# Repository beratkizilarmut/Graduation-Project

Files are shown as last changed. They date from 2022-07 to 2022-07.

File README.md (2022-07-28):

# Graduation-Project

2021/2022

Graduation Project Personal Works of

Berat Kizilarmut, Electronics Engineering Student at Gebze Technical University

Ömer Emre Polat, Electronics Engineering Student at Gebze Technical University

In daily life, users are integrating wearable technology products into their lives
more and more day by day. This technological revolution, which started with the daily
use of smart phones, continues to accelerate in the market with products such as smart
watches and smart wristbands. Smart glasses, which are new types of wearable
technology products that include augmented reality in the past years, have not received
a great acceptance in the market yet. The reason why these wearable technology
products, which bring the border between reality and information technologies closer
together, have not yet found a place in the market, is that smart glasses and their
derivatives are not attractive to users in terms of their design and their costs are
relatively high. For this reason, the project was made on the design of an external smart
glasses apparatus with a lower cost and where the users can change the onboard
software according to their needs and their desired functionality

Development board used in the Bluetooth Based External Smart Glass Apparatus is ESP32-WROOM-32D. Development environment is Platform.IO and operating system is FreeRTOS.

Graduation project report provided is written in Turkish.

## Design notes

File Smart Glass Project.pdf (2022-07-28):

# Introduction

In daily life, users are integrating wearable technology products into their lives more and more

day by day. This technological revolution, which started with the daily use of smart phones,

continues to accelerate in the market with products such as smart watches and wristbands.

Smart glasses, which are new types of wearable technology products that include augmented

reality in the past years, have not received a great acceptance in the market yet. The reason why

these wearable technology products, which bring the border between reality and information

technologies closer together, have not yet found a place in the market, is that smart glasses and

their derivatives are not attractive to users in terms of design and their costs are high. Our top

priority is accessibility and customization to solve this very problem.

# Current Implementation

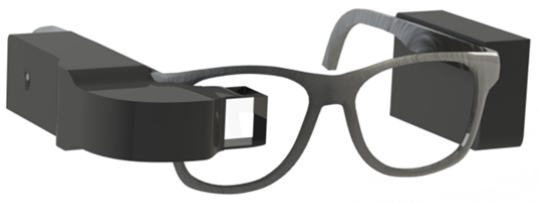
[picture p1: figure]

Current implementation which was our graduation project from electronics engineering is made

up from two distinct modules. First module contains the microcontroller unit, capacitive touch

user interface and the optical package that user view's. Second module contains the battery,

voltage boost and battery charging circuit. Apart from the body of the smart glass, every

component used is off the shelf and is open to further optimization opportunities.

# Use Cases

Main use case for the current implementation is displaying necessary smart phone information

to the user seamlessly, such as time and application notifications. Improvement for this use case

would be implementing support for other applications such as maps which would be useful for

drivers to check their map without obstructing their view. Another use case could be that for

deaf people, the device could perform speech recognition through the use of a speech

recognition API with the Wi-Fi of the phone and display the recognized speech to the deaf

person.

# Technical Details

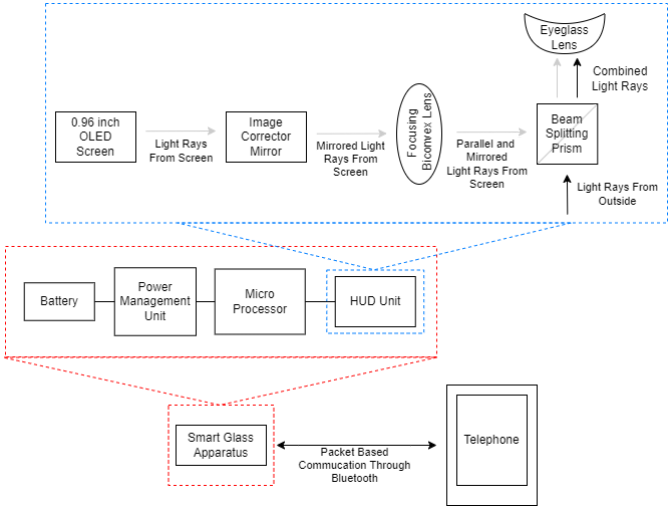
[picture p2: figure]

The software of the microcontroller, which is 'Espressif ESP32-WROOM-32D', is written in an

efficiency-oriented manner aiming for low power consumption. Software has been developed

with the help of the 'Arduino Framework' on the 'C++' software language and the 'PlatformIO'

plug-in using 'FreeRTOS' open source operating system. The advantage of this operating system

type is that more than one process can be performed at the same time, various processes can be

run on selected cores, and task assignment for operations. Power Delivery Unit consists of

'Adafruit Powerboost 1000C' Li-Ion Battery Charging and Voltage Booster circuit and the

2000mAh 3.7V Lithium-Ion battery. As for the optical details, a generic 0.96 inch OLED screen is

located at the back of the optical housing. Image rendered at the display is reflected upon the

mirror to direct it to the biconvex lens. Image with focal length aligned to human perception is

combined with background image at the beam-splitting prism and this combined image is then

viewed by the user.

# Improvement Plans

Microcontroller development board that is currently used is not utilized fully GPIO-wise. An

integrated circuit board with this very microprocessor and desired display embedded in one will

massively cut the physical size of the board thus decrease the footprint of the smart glass body.

By utilizing mirrored images on the display itself, need for the correcting view mirror can be eliminated and overall size of the smart glass body can be decreased even more. These two past

improvement plans will decrease the already low cost of the product. Rather than further cost

and size improvements, electronics improvement which open the doors to more hardware

intensive wearable technology implementations. With better hardware protocols such as

'Android Auto' and 'Apple CarPlay' can be utilized to give users heads-up display experience for

any application they want for example maps.

# Final Words

As a duo of engineers, we are interested in improving our project even further to fill the wearable

technology deficiency for glasses wearing tech enthusiasts. We are interested and open to

improve ourselves further in embedded system technologies.

# Contacts

Berat Kızılarmut - beratkizilarmut@gmail.com - +905393040726

Ömer Emre Polat - omeremrepolat1@hotmail.com - +905439034947

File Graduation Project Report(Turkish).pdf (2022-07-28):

T.C.

## GEBZE TEKNİK ÜNİVERSİTESİ

## MÜHENDİSLİK FAKÜLTESİ

## BLUETOOTH TABANLI HARİCİ AKILLI

## GÖZLÜK APARATI

## ÖMER EMRE POLAT

## BERAT KIZILARMUT

## LİSANS BİTİRME-II PROJESİ RAPORU

## ELEKTRONİK MÜHENDİSLİĞİ BÖLÜMÜ

### DANIŞMANI

### DR. TUBA GÖZEL

## GEBZE

2022

T.R.

## GEBZE TECHNICAL UNIVERSITY

## ENGINEERING FACULTY

## BLUETOOTH BASED EXTERNAL

## SMART GLASS APPARATUS

## ÖMER EMRE POLAT

## BERAT KIZILARMUT

## UNDERGRADUATE THESIS

## GRADUATION-II PROJECT REPORT

## ELECTRONICS ENGINEERING DEPARTMENT

### THESIS SUPERVISOR

### DR. TUBA GÖZEL

## GEBZE

2022

GEBZE TEKNİK
ÜNİVERSİTESİ | LİSANS JÜRİ ONAY FORMU
GTÜ Mühendislik Fakültesi Yönetim Kurulu’nun | / | /.. | tarih ve
..………/ | sayılı kararıyla oluşturulan jüri tarafından | / | /.. | tarihinde tez
savunma | sınavı | yapılan | | ’ın | tez | çalışması
| Anabilim Dalında LİSANS tezi olarak kabul edilmiştir.

JÜRİ

ÜYE

(TEZ DANIŞMANI) :

ÜYE | :
ÜYE | :

ONAY
Gebze Teknik Üniversitesi | Enstitüsü Yönetim Kurulu’nun
...…/.…../ | tarih ve ….…/ | sayılı kararı.

i

## ÖZET

Günlük hayatta kullanıcılar giyilebilir teknoloji ürünlerini hayatlarına günden

güne daha fazla entegre etmektedirler. Akıllı telefonların günlük kullanımı ile başlayan

bu teknolojik devrim, akıllı saat ve akıllı bileklik gibi ürünler ile markette

ivmelenmeye devam etmektedir. Google ve Microsoft gibi firmaların da geçtiğimiz

yıllarda artırılmış gerçeklik barındıran yeni tür giyilebilir teknoloji ürünleri olan akıllı

gözlükler ise henüz markette büyük bir kabul görmemiştir. Kullanıcıların gerçeklik ile

bilgi teknolojileri arasındaki sınırı birbirine yakınlaştıran bu giyilebilir teknoloji

ürünlerinin markette henüz bir yer edememesinin sebebi akıllı gözlük ve türevlerinin

tasarım olarak kullanıcılara çekici gelmemesi ve maliyetlerinin yüksek olmasıdır. Bu

sebeple yapılan proje daha düşük maliyette ve kullanıcıların istediği işleve göre

yazılımını değiştirebileceği bir harici akıllı gözlük aparatı tasarlanması üzerine

yapılmıştır.

Anahtar Kelimeler: Giyilebilir Teknoloji, Akıllı Gözlük, Gömülü Sistemler,

Optik

ii

## SUMMARY

In daily life, users are integrating wearable technology products into their lives

more and more day by day. This technological revolution, which started with the daily

use of smart phones, continues to accelerate in the market with products such as smart

watches and smart wristbands. Smart glasses, which are new types of wearable

technology products that include augmented reality in the past years, have not received

a great acceptance in the market yet. The reason why these wearable technology

products, which bring the border between reality and information technologies closer

together, have not yet found a place in the market, is that smart glasses and their

derivatives are not attractive to users in terms of their design and their costs are

relatively high. For this reason, the project was made on the design of an external smart

glasses apparatus with a lower cost and where the users can change the onboard

software according to their needs and their desired functionality.

Key Words: Wearable Tech, Smart Eyeglasses, Embedded Systems, Optics

iii

## TEŞEKKÜR

Başta, lisans eğitimimizde ve akademik hayatımızda desteğini ve yardımlarını

hiçbir zaman esirgemeyip bilgisi ile bu çalışmanın oluşmasının yolunu açan

danışmanımız Dr. Tuba Gözel’e ve atölyelerini tarafımız kullanımına açan Gebze Teknik Üniversitesi Robotik ve Otomasyon Kulübü’ne teşekkürlerimizi sunarız.

iv

## İÇİNDEKİLER

| Sayfa
ÖZET | i
SUMMARY | ii
TEŞEKKÜR | iii
İÇİNDEKİLER | iv
SİMGELER ve KISALTMALAR DİZİNİ | v
ŞEKİLLER DİZİNİ | vi
TABLOLAR DİZİNİ | vii
1. GİRİŞ 1.1. Projenin Amacı, Katkısı ve İçeriği 1.2. Projenin Kapsamı 1.3. Literatür Taraması 1.3.1. Işın Ayırıcı Prizma 1.3.2. Kapasitif Dokunmatik Arayüz | 1 2 2 2 3 3
2. PROJE YÖNTEMİ | 4
2.1. Malzeme Listesi
2.1.1. Mikro Denetleyici Ünitesi
2.1.2. Ekran Ünitesi
2.1.3. Batarya
2.1.4. Batarya Şarj ve Yükseltici Ünitesi
2.1.5. Işın Ayırıcı Prizma
2.1.6. Lens
2.1.7. Bütçe
2.2. Donanım Tasarımı
2.3. Mikro Denetleyici Yazılımı
2.3.1. Ana İşlevsellik
2.3.2. Gözlük İşlevselliği Kütüphanesi
2.3.3. Görüntü İşlevselliği Kütüphanesi
2.3.4. Bluetooth İşlevselliği Kütüphanesi
2.3.5. Giriş Çıkış İşlevselliği Kütüphanesi
2.4. Mobil Cihaz Uygulaması

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
3. Ürün Değerlendirilmesi 3.1. Mobil Cihaz Uygulaması 3.2. Bluetooth Tabanlı Harici Akıllı Gözlük Ünitesi | 14 14 15
4. Sonuçlar ve Yorumlar | 16
5. Öneriler ve Geliştirmeler | 17
KAYNAKÇA | 17

v

## SİMGELER ve KISALTMALAR DİZİNİ

Simgeler ve

Kısaltmalar

Açıklamalar

RISC | : Reduced Instruction Set Architecture (İndirgenmiş Komut Takımlı
| Mimari)
SPI | : Serial Peripheral Interface (Seri Çevre Birimi Arayüzü)
OLED | : Organic Light Emitting Diode (Organik Işık Saçılımlı Diyot)
HUD | : Head-Up Display (Baş Üstü Göstergesi)
Wi-Fi | : Wireless Field (Kablosuz Ağ)

vi

## ŞEKİLLER DİZİNİ

Şekil No: | Sayfa
1.1: | Bluetooth Tabanlı Harici Akıllı Gözlük Aparatı | 1
1.3.1.1: | Işın Ayırıcı Prizma çalışma prensibi diyagramı | 3
2.1: | Akıllı Gözlük Aparatı Bağlantı ve İletişim Diyagramı | 4
2.2.1: | Donanım Tasarımı Üç Boyutlu Modeli | 8
2.2.2: | Ekran, ayna, lens ve ışın ayırıcı prizma geometrik diyagramı | 9
2.3.1: | ESP32-WROOM-32D Mikro Denetleyici | 9
2.3.2: | Mikro Denetleyici Yazılım Akış Diyagramı | 10
2.4.1: | Mobil Uygulama Yazılım Akış Diyagramı | 13
3.1.1: | Yapılan Mobil Uygulamanın Emülatör Üzerinde Denenmesi | 14
3.2.1: | Kullanıcı tarafından görülen görüntü örneği | 15
4.1: | Bluetooth Tabanlı Harici Akıllı Gözlük Aparatı | 16

vii

## TABLOLAR DİZİNİ

Tablo No: | Sayfa
2.1.7.1: | Bluetooth Tabanlı Harici Akıllı Gözlük Aparatı Malzeme Listesi

ve Bütçesi

7

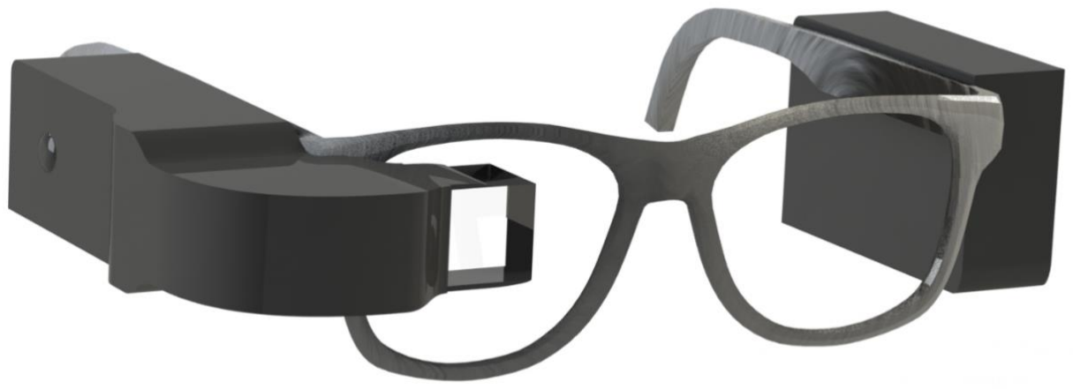
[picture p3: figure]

1

## 1. GİRİŞ

Günlük hayatta kullanıcılar giyilebilir teknoloji ürünlerini hayatlarına günden

güne daha fazla entegre etmektedirler. Akıllı telefonların günlük kullanımı ile başlayan

bu teknolojik devrim, akıllı saat ve bileklik gibi ürünler ile markette ivmelenmeye

devam etmektedir. Google ve Microsoft gibi firmaların da geçtiğimiz yıllarda

artırılmış gerçeklik barındıran yeni tür giyilebilir teknoloji ürünleri olan akıllı

gözlükler ise henüz markette büyük bir kabul görmemiştir. Kullanıcıların gerçeklik ile

bilgi teknolojileri arasındaki sınırı birbirine yakınlaştıran bu giyilebilir teknoloji

ürünlerinin markette henüz bir yer edememesinin sebebi akıllı gözlük ve türevlerinin

tasarım olarak kullanıcılara çekici gelmemesi ve maliyetlerinin yüksek olmasıdır.

Şekil 1.1: Bluetooth Tabanlı Harici Akıllı Gözlük Aparatı

2

## 1.1. Projenin Amacı, Katkısı ve İçeriği

Her telefona ve her gözlüğe uyum sağlayabilecek, kullanımı kolay ve gündelik

hayata negatif etki etmeyecek bir harici akıllı gözlük aparatı çözümü üretmek. Bu

gözlük aparatı kullanıcının gözüne polarize optik çözümleri ile sahip olunan bilgileri

yansıtacak. Gözlüğün işlem merkezi olarak ‘RISC’ temelli bir mikro denetleyici

ünitesi kullanılacak. Mikro denetleyici ünitesinde gömülü durumda bulunan

'Bluetooth' modülü aracılığı ile gözlüğün, 'Bluetooth' uyumlu telefon arasında iletişimi

sağlanacak. Gözlüğün konfigürasyonları telefonda bulunan uygulama aracılığı ile

yapılacak. Modüler teknolojisi ile kullanıcının tercihindeki gözlüğe adapte edilebilen

bir ürün olacak.

## 1.2. Projenin Kapsamı

Giyilebilir teknoloji marketindeki bir sonraki adım olan akıllı gözlük

çözümlerinin kullanıcılara daha uygun fiyatlarla ve daha geniş bir gözlük yelpazesine

uygulanabilir hale getirilmesi.

Proje sayesinde:

-Daha ulaşılabilir fiyatlarda bir akıllı gözlük çözümü.

-Kullanıcıların kendi gözlüklerine uyum sağlayan modüler bir yapı.

-Modüler yapısından dolayı tamir edilebilir olması.

-Açık kaynak temelli olması.

-Yazılımsal olarak modüler olması, modifikasyonlara ve kişiselleştirmelere açık

olması.

## 1.3. Literatür Taraması

Bluetooth Tabanlı Harici Akıllı Gözlük Aparatı Projesinin geliştirme aşamasında

araştırılan ve projede kullanılan teknolojilerin özet bilgileri verilmiştir.

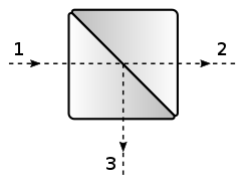
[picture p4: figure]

3

### 1.3.1. Işın Ayırıcı Prizma

Işın ayırıcı [1], bir ışık hüzmesini ikiye ayıran bir optik araçtır. Genellikle yapı

olarak iki adet yarım küp prizmanın araya çeşitli kaplamalar eklenip yapıştırılması ile üretilir. İki yarım prizma arasındaki kaplama prizmanın ışın bölme oranını (çoğunlukla

%50 ye %50) ve etkili bulunduğu dalga boyu gibi parametreleri ayarlamak için

kullanılır. Işın ayırıcı prizmalar hem gelen ışık hüzmesini iki ayrı hüzmeye bölebilir,

Şekil 1.3.1.1’de gösterildiği gibi, hem de ayrı yönlerden gelen iki ışık hüzmelerini

birleştirip tek bir yönden iletebilirler.

Şekil 1.3.1.1: Işın Ayırıcı Prizma çalışma prensibi diyagramı

### 1.3.2. Kapasitif Dokunmatik Arayüz

Kapasitif Dokunmatik Arayüzler [2] bir insan dokunuşu veya iletken

dokunuşunu tespit edebilen iletişim arayüzleridir. Kapasitif arayüze temas

edildiğinde temas noktasında küçük bir miktar elektrik yükü çekilerek işlevsel bir

kapasitör oluşturulur. Bu oluşan kapasitör ve kapasitans değeri bir mikro denetleyici

tarafından tespit edilebilir ve bir giriş arayüzü olarak kullanılabilir. Bu metot

mekanik, hareket eden parçalar bulundurmadığı için uzun ömürlü bir buton tipi

olarak sunulmaktadır.

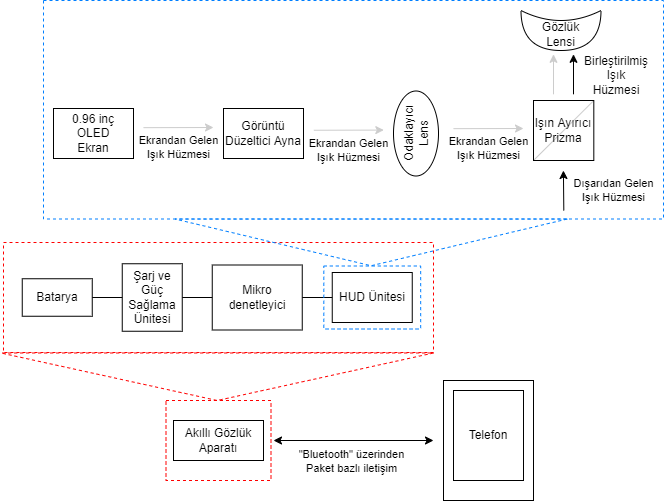
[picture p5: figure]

4

## 2. PROJE YÖNTEMİ

Şekil 2.1: Akıllı Gözlük Aparatı Bağlantı ve İletişim Diyagramı

Bluetooth Tabanlı Harici Akıllı Gözlük Aparatı Projesi, diyagramı yukarıda Şekil

2.1’de verilmiş bulunan, çalışma yöntemi olarak akıllı telefonda bulunan mobil

uygulama sayesinde ‘Bluetooth’ aracılığı ile mikro denetleyici ünitesi ile iletişim

kuracaktır. Mobil uygulama tarafından alınan veriler mikro denetleyici tarafından

işlenecek ve optik işlemler sonucunda kullanıcının gözüne yansıtılacaktır. Bluetooth

Tabanlı Harici Akıllı Gözlük Aparatı Projesi üç alana bölünüp incelenmiştir. Raporda

malzeme listesinin ardından öncelikle optik çözüm, kullanıcı ara yüzü ve elektronik

donanımı barındıran fiziksel donanım tasarımı incelenecektir. Bu kısım mikro

denetleyici mobil uygulama aracılığı ile gönderilen verileri kullanarak gözlük görüntü

işlevselliklerini düzenleyecek ve çıkış verecektir. Dahilinde bulunan batarya ve güç

üniteleri ise hem mikro denetleyiciyi hem de görüntü işlevlerine gerekli enerjiyi

sağlayacaktır. Fiziksel yapının ardından mikro denetleyici ünitesinde çalışmakta olan

‘Bluetooth’ iletişim işlevselliği, görüntü çıktı fonksiyonları ve kullanıcı ara yüz

5

fonksiyonları gibi işlevsellikleri barındıran mikro denetleyici yazılımı incelenecektir.

Ardından bu kısımlardan sonuncusu olan akıllı telefon ile mikro denetleyici ünitesi

arasında iletişimi sağlayan, telefondan işlevsellikler için gerekli olan bilgilerin

alınmasını sağlayan ve kullanıcı ayarlarının yapılmasına olanak sağlayan mobil

uygulama incelenecektir.

## 2.1. Malzeme Listesi

Bluetooth Tabanlı Harici Akıllı Gözlük Aparatı Projesinde kullanılmak üzere

seçilen parçalar ve seçilme nedenleri.

### 2.1.1. Mikro Denetleyici Ünitesi

Mikro denetleyici ünitesi olarak, kendi 'Bluetooth' ve 'Wi-Fi' iletişim ünitesi

içinde olması, kapasitif sezi özelliğine sahip olması, boyut faktörünün kullanımımıza

uygun olması, performansına göre güç harcaması az olması, fiyatının uygun olması

ve bulunabilirliği kolay olması sebeplerinden dolayı ESP32-WROOM-32D [3]

modeli seçilmiştir.

### 2.1.2. Ekran Ünitesi

Görüntü çıkışı alınması için ekran ünitesi olarak küçük boyutu, ‘SPI’ iletişim

protokolü, yüksek parlaklığı ve uygun fiyatından dolayı markasız 0,96 inç OLED

80x160 SPI Ekran [4] seçilmiştir.

### 2.1.3. Batarya

Sisteme güç sağlaması için batarya elimizde bulunduğu için 3.7V 2000mAh Lityum-İyon bir batarya kullanılmıştır. Batarya tercihi olarak Lityum-İyon batarya

seçilmesinin sebebi diğer batarya teknolojilerine göre birim boyuta kıyaslandığında

enerji yoğunluğunun yüksek olmasıdır.

6

### 2.1.4. Batarya Şarj ve Yükseltici Ünitesi

Lityum-İyon tip batarya kullanıldığı için, lityum-iyon bataryaların özel

gereksinimlerini sağlayan ve kendi içerisinde 3.7V gerilimi mikro denetleyicinin

kullandığı 5V gerilime yükselten Adafruit Powerboost 1000C Batarya Şarj ve Yükseltici Ünitesi elimizde bulunduğu için ve gereksinimleri sağladığı için

kullanılmıştır.

### 2.1.5. Işın Ayırıcı Prizma

Optik işlemlerde 18 mm en, 18 mm boy ve 18 mm yüksekliğe sahip, 50:50

bölme oranına sahip ve görünür ışık dalga boyunda işlevselliğe sahip bir ışın ayırıcı

prizma kullanılmıştır. Geçirgenlik oranı olarak 50:50 seçilmesinin sebebi ekran

parlaklığı ile ortam ışığı seviyesinin denk tutulmasının amaçlanmasıdır.

### 2.1.6. Lens

Optik işlemlerde kullanıcının gözünün yorulmaması için görüntünün odak noktasını kaydıran 45 mm odak uzaklığına sahip bir lens kullanılmıştır. Özel tasarım

lens üretilmesinin masraflı olmasından dolayı projedeki optik çözümlere uyum

sağlayabilen özelliklere sahip ‘Google Cardboard’ yapay gerçeklik gözlüğünün

lensleri tercih edilmiştir.

### 2.1.7. Bütçe

Bluetooth Tabanlı Harici Akıllı Gözlük Aparatı Projesinde kullanılan

malzemeler ve fiyatları Tablo 2.1.7.1’de verilmiştir.

7

Tablo 2.1.7.1 Bluetooth Tabanlı Harici Akıllı Gözlük Aparatı Malzeme

Listesi ve Bütçesi

Ürün ismi | Adet | Fiyat | Link
ESP32-WROOM-32D | 1 | 131,2 7 TL | https://www.direnc.net/esp32-wroom-32d-wifi-bluetooth-gelistirme-modulu
PowerBoo st 1000C | 1 | 327,2 6 TL | https://www.adafruit.com/product/2465
3.7V 2000 mAh Li-Ion Batarya | 1 | 108,5 9 TL | https://www.direnc.net/37v-2000-mah-li-polymer-pil
tinylab 3D 1.75 mm Siyah PLA Filament | 1 | 239,9 9 TL | https://www.amazon.com.tr/tinylab-1-75-Siyah-PLA-Filament/dp/B08DJ3XC3W/
0.96 inch SPI OLED Ekran | 1 | 104,3 7 TL | https://www.direnc.net/096-inch-oled-arduino-spi-tft-ekran
18*18*18 Işın Ayırıcı Prizma | 1 | 156,4 1 TL | https://tr.aliexpress.com/item/1005001279808206 .html
Google Cardboard 25mm Lens | 1 | 9,90 TL | https://urun.n11.com/giyilebilir-teknoloji-aksesuarlari/toptan-25mm-sanal-gerceklik-gozlugu-google-cardboard-lens-25-mm-P377565747
5*5 Pleksi Ayna | 1 | 20,40 TL | https://urun.n11.com/diger/3mm-gumus-renk-ayna-pleksi-istediginiz-olcude-lazer-kesim-P441922073
TOPLAM | | 1097,80 TL

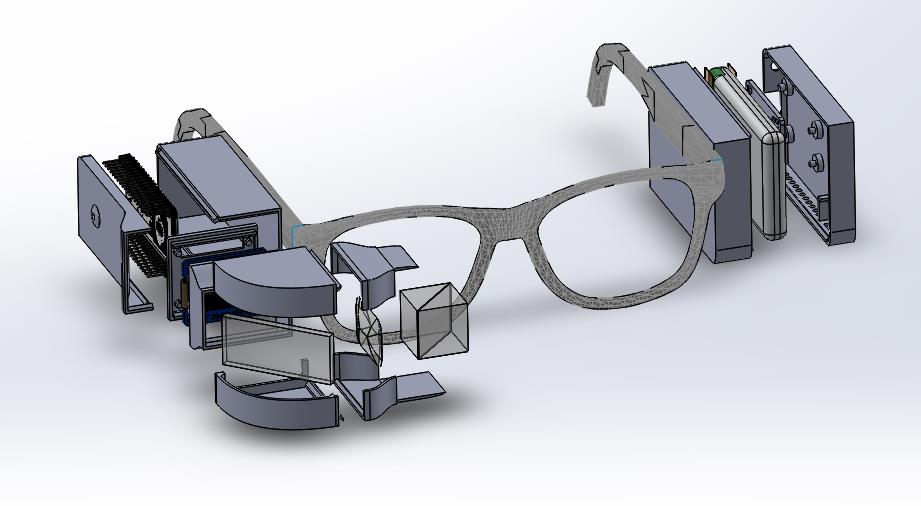
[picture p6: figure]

8

## 2.2. Donanım Tasarımı

Şekil 2.2.1: Donanım Tasarımı Üç Boyutlu Modeli

Bluetooth Tabanlı Harici Akıllı Gözlük Aparatı Projesinin işlevselliği için

kullanımına karar verilen elektronik ve optik malzemelerin bir araya getirilebilmesi

için bir donanım tasarımı yapılmıştır. Tasarım için Bilgisayar Destekli Tasarım

Programı olan ‘Solidworks’ kullanılmış, tasarımlar üç boyutlu yazıcı aracılığı ile PLA malzeme kullanılarak üretilmiştir. Donanım üç parçaya ayrılarak incelenmiştir. İlk

parça olarak mikro denetleyici ünitesi ve kapasitif dokunmatik ara yüzü barındıran bölme oluşturulmuştur. İkinci parça olarak Lityum-İyon batarya, Batarya Şarj ve

Yükseltici Ünitesi ve açma kapama anahtarı bulunan güç ünitesi bölmesi

oluşturulmuştur. Kullanılmakta olan güç ünitesi teorik olarak toplamda 450mW güç

kullanan mikro denetleyici ünitesi ve ekran ünitesini 16 saat olarak besleyebilecek kapasiteye sahiptir. Üçüncü parça olarak 0,96 inç OLED ekranı, görüntü düzeltici

aynayı, görüntü odaklayıcı lensi ve ışın ayırıcı prizmayı barındıran bir bölme

oluşturulmuştur. Bu bölmenin boyutları istenilen optik etkinin oluşturulabilmesi için,

geometrisi Şekil 2.1.2’ de verilmiş olan, matematiksel hesaplamalar sonucu elde

edilmiştir. Ekran, ayna ve ışın ayırıcı prizma arasındaki mesafe yaklaşık 45mm olduğu

için ayna ile ışın ayırıcı prizma arasına 45 mm odak mesafeli lens yerleştirilmiştir. Bu

lens sayesinde kullanıcı görüntüyü odaklanma sorunu yaşamadan daha rahat bir

şekilde görebilmektedir.

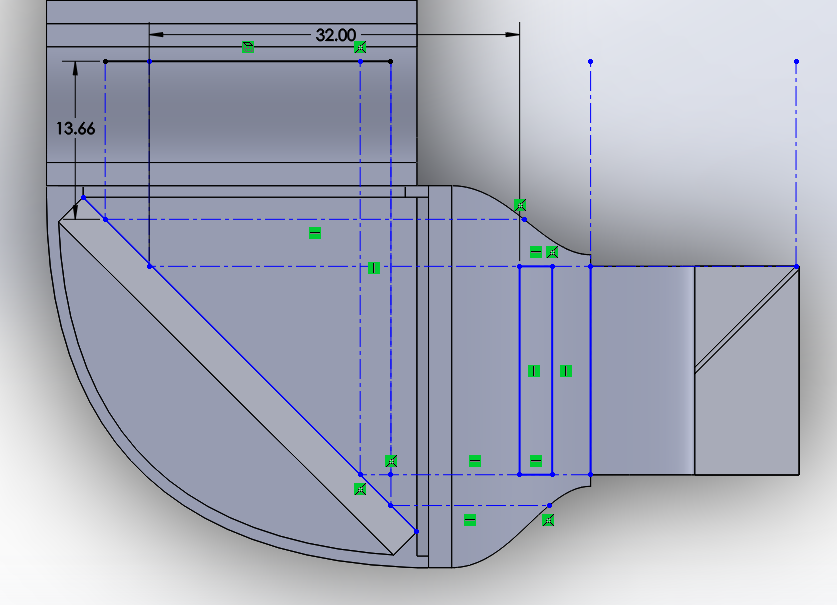
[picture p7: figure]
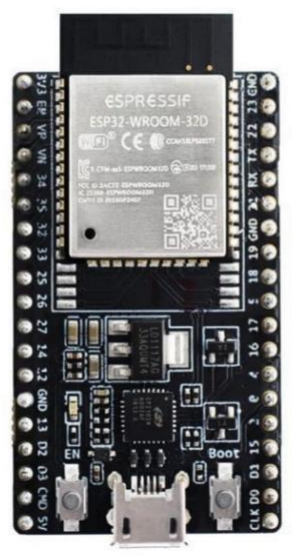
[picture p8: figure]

9

Şekil 2.2.2: Ekran, ayna, lens ve ışın ayırıcı prizma geometrik diyagramı

## 2.3. Mikro Denetleyici Yazılımı

Mikro denetleyici, Şekil 2.2.1, üzerinde bulunan yazılım düşük güç tüketimini

amaçlayarak verim odaklı şekilde yazılmaktadır. Mikro denetleyici geliştirme

aşamasında yazılım sürecinde ‘C++’ yazılım dili ile 'Visual Studio Code' programında

'PlatformIO' eklentisi aracılığı ile çalışılıp, 'Arduino Framework' yardımıyla

hazırlanmıştır. Yazılımda ayrıca 'FreeRTOS' açık kaynak işletim sistemi

kullanılmıştır. Bu işletim sisteminin avantajı birden fazla işlemin aynı anda

yapılabilmesi, çeşitli işlemlerin seçilen çekirdeklerde çalıştırılması ve sürekli yapılan

işlemler için görev ataması yapılabilmesidir.

Şekil 2.3.1: ESP32-WROOM-32D Mikro Denetleyici

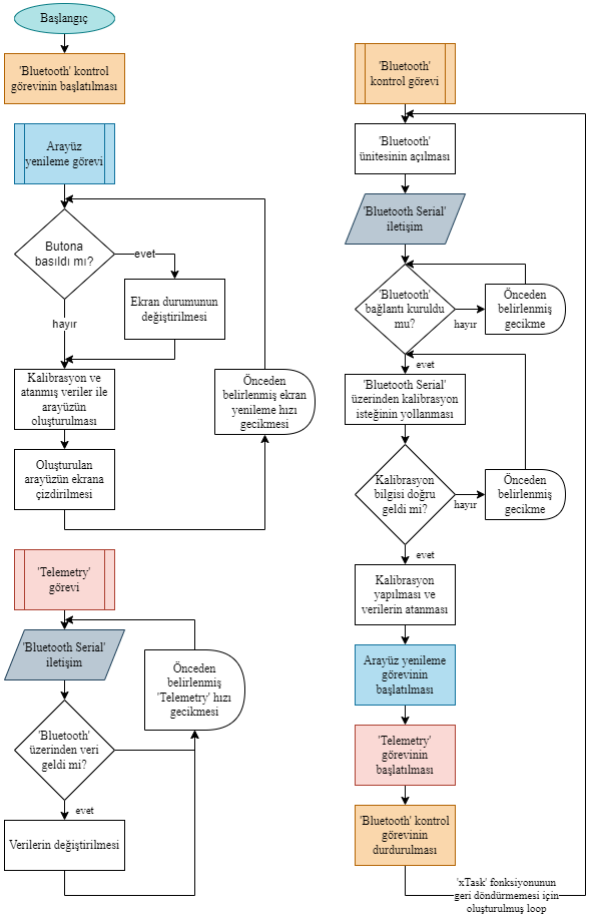
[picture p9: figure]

10

Şekil 2.3.2: Mikro Denetleyici Yazılım Akış Diyagramı

11

Mikro denetleyicinin çalışma prensiplerini barındıran akış diyagramı Şekil

2.2.2’de verilmiştir. Mikro denetleyici işlevleri olarak tasarlanan fonksiyonlar ve

kütüphaneler sıradaki kısımlarda ayrı ayrı incelenmiştir.

### 2.3.1. Ana İşlevsellik

Yazılımın temeli olan ‘main.cpp’ Ek-A dosyasında bütün proje kapsamında
kullanılan | hazır | kütüphaneler | (Örn:’Arduino.h’, | ‘BluetoothSerial.h’,

‘Adafruit_SSD1306.h’, ‘SPI.h’ ve ‘TFT_eSPI.h’), proje için özel olarak tarafımızdan
yazılmış | olan | kütüphaneler | (Örn: | ‘BluetoothUtils.h’, | ‘DisplayUtils.h’ | ve

‘GlassUtils.h’) çağırılmıştır. Bu çağırmaların ardından ‘GlassUtils Glass;’ aracılığıyla

gözlük işlevsellik sınıfı oluşturulmuş, kurulum ayarlarının başlatılmasından itibaren

yazılımın mobil cihaz uygulaması ile iletişim protokolleri başlatılmış ve görüntü çıkış

operasyonları harekete geçirilmiştir.

### 2.3.2. Gözlük İşlevselliği Kütüphanesi

Mikro denetleyici yazılımında bütün kütüphanelerin ve işlevselliklerin hiyerarşik olarak en tepesinde bulunan kütüphane ‘Gözlük İşlevselliği Kütüphanesi’

‘GlassUtils.cpp’ Ek-B ve ‘GlassUtils.h’ Ek-C dosyalarıdır. Diğer kütüphaneler bu

kütüphane dahilinde üye sınıf objesi olarak tutulmaktadır. Bu kütüphane bünyesinde diğer kütüphanelerden (Örn:’IOUtils.h’) alınan bilgiler diğer kütüphanelere

aktarılmakta ve aralarındaki iletişim sağlanmaktadır. ‘FreeRTOS’ platformunun

sağlamış olduğu sürekli çalışan işlemler işlevselliği bu kütüphanede kullanılmakta

olup düzenli işlemler bu kütüphanede başlatılmaktadır.

### 2.3.3. Görüntü İşlevselliği Kütüphanesi

Mikro denetleyici görüntü çıkışları bu kütüphanede yapılmaktadır. Kütüphane

‘DisplayUtils.cpp’ Ek-D ve ‘DisplayUtils.h’ Ek-E dosyalarından oluşmaktadır. Bu

kütüphane ‘Bluetooth’ aracılığı ile iletilen verilerin işlenilmesi, görüntü çıkışlarının

12

alınması, görüntü hizalama ayarlarının yapılması, buton ve durum işlevselliklerin

çalışması görevlerini üstlenmektedir.

### 2.3.4. Bluetooth İşlevselliği Kütüphanesi

Bluetooth İşlevselliği Kütüphanesi mikro denetleyici ünitesi ile mobil cihaz

uygulaması arasındaki ‘Bluetooth’ iletişim protokolünün başlatılması ve gelen

verilerin gerekli kütüphanelere yönlendirilmesi işlevselliklerini gerçekleştirmektedir.

Kütüphane ‘BluetoothUtils.cpp’ Ek-F ve ‘BluetoothUtils.h’ Ek-G dosyalarından

oluşmaktadır. ‘Bluetooth’ verileri bu kütüphanede işlenmemektedir, bu kütüphane

sadece iletişim kanalı olarak kullanılmaktadır.

### 2.3.5. Giriş Çıkış İşlevselliği Kütüphanesi

Giriş Çıkış İşlevselliği Kütüphanesi kapasitif buton üzerinde bulunan kapasitans

değerlerini sürekli değerlendirip kapasitansta dokunma sebebi ile gerçekleşen

değişikliği tespit edip üst üste birden fazla hatalı buton aksiyonu tanımlamaksızın giriş işlevselliklerini gerçekleştirip bu bilgileri Görüntü İşlevselliği Kütüphanesine

aktarmaktadır. Kütüphane ‘IOUtils.cpp’ Ek-H ve ‘IOUtils.h’ Ek-I dosyalarından

oluşmaktadır.

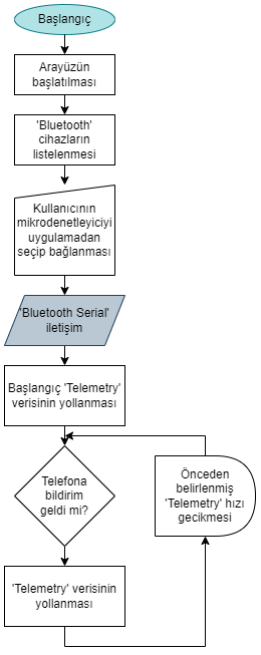
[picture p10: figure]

13

## 2.4. Mobil Cihaz Uygulaması

Mobil cihaz ve mikro denetleyici ünitesinin arasında iletişim kurulması için

'Bluetooth Serial' protokolü yardımı ile bir 'Android 9.0' tabanlı, akış diyagramı Şekil

2.3.1’de | verilen, | uygulama | geliştirilmiştir. | Uygulama | ‘Android | Studio’

uygulamasında geliştirilip, terminal kısmı 'SimpleBluetoothTerminal' [5] isimli açık

kaynaklı bir uygulamadan türetilmiştir. Bu uygulama aracılığı ile mobil cihazdan

mikro denetleyici ünitesine ve mikro denetleyici ünitesinden mobil cihaza çift taraflı

iletişim kurulabilmektedir. Bu uygulama sayesinde akıllı gözlük aparatı ile

kullanıcıların telefonları arasında bağlantı kurulmaktadır. Mikro denetleyici ünitesi

saat ve benzeri bilgileri eşitlemek için kullanıcının telefonunu kullanılmaktadır.

Uygulamada seçilen bildirim ayarlarına göre telefondaki bildirimler ile ilgili veri

mikro denetleyiciye gönderilebilmektedir. Uygulama bünyesindeki terminal aracılığı

ile mobil cihazdan mikro denetleyici ünitesi kontrol edilebilmektedir.

Şekil 2.4.1: Mobil Uygulama Yazılım Akış Diyagramı

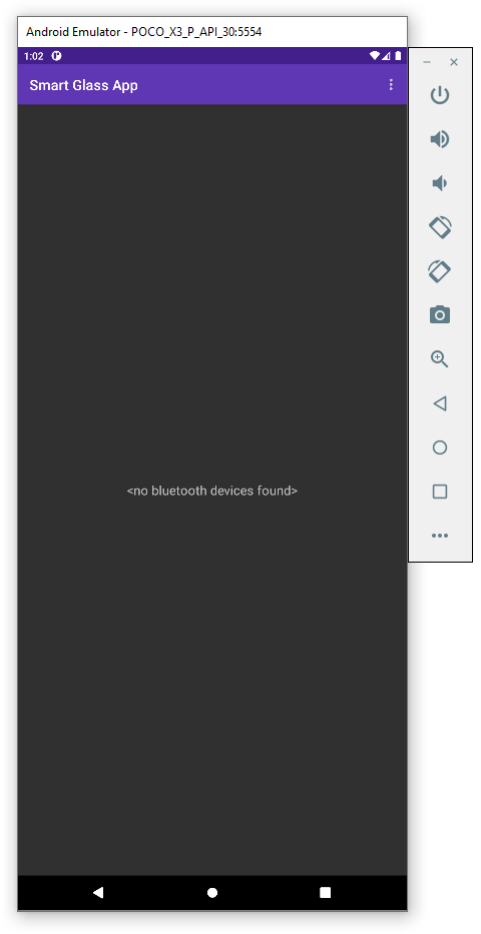
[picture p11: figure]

14

## 3. ÜRÜN DEĞERLENDİRMESİ

## 3.1. Mobil Cihaz Uygulaması

Mobil cihaz üzerinden yapılan ve bilgisayar ortamında yapılan ‘Android’

emülatörü, Şekil 3.1.1., ile yapılan testlerde, mikro denetleyici ile arasında iletişim

sağlanabilmiştir. Bu iletişim tek taraflı olarak kullanılmaktadır.’Android’ mobil

cihazdan otomatik olarak saat ve konum bilgileri alınamamaktadır. Terminal

komutları ile manuel şekilde gönderilmeleri gerekmektedir.

Şekil 3.1.1: Yapılan Mobil Uygulamanın Emülatör Üzerinde Denenmesi

Aynı şekilde testler, ‘Android’ telefon üzerinden de yapılmıştır ve bu durumda

veri paketleri düzeyinde iletişim sağlanabilmiştir.

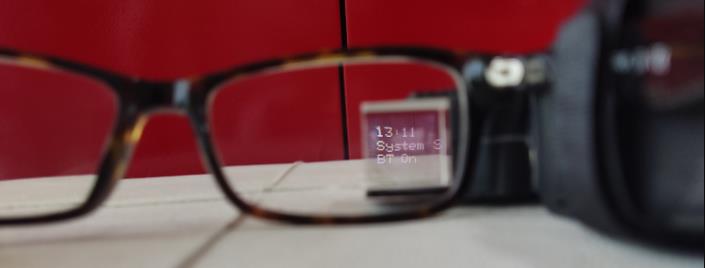
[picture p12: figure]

15

## 3.2. Bluetooth Tabanlı Harici Akıllı Gözlük Aparatı Ünitesi

Bluetooth Tabanlı Harici Akıllı Gözlük Aparatı Ünitesi başarılı bir şekilde

üretilmiş ve birleştirilmiş olup hedeflenen tasarım özelliklerine ulaşılmıştır.

Gözlüğün sol tarafına yerleştirilen, batarya ve şarj ünitesini barındıran güç ünitesi 56g

ağırlığa sahip olmuştur. Gözlüğün sağ tarafına yerleştirilen, optik çözüm ve mikro

denetleyiciyi barındıran akıllı gözlük aparatı ünitesi 58g ağırlığa sahip olmuştur.

Ortalama güç tüketimi ve batarya kapasitesi hesaplarına göre sürekli aktif kullanımda

ünitenin 16 saat batarya ömrüne sahip olacağı tespit edilmiştir. Kullanıcı konforu ve

kullanım alanları hedeflerine başarıyla ulaşılmıştır. Gözlük camı ve prizma arasındaki

mesafenin kişiden kişiye ve gözlükten gözlüğe değişmesinden dolayı oluşan optik

uyumsuzlukları | çözmek | için | kullanıcı | arayüzü | kişisel | tercihlere | göre

konumlandırılabilir hale getirilmiştir.

Tasarım boyut kısıtlamalarından dolayı mekanik butonlar yerine kapasitif buton

kullanılmıştır. Bu kapasitif buton sayesinde alan daha verimli kullanılmasına rağmen

ürün paketlemesinde boyut problemleri yaşanmış olup, daha hafif ve daha konforlu bir

ürün üretilmesi için özel üretim devre kartlarına ve malzemelere ihtiyaç duyulmaktadır. Kullanılan Lityum-İyon batarya bu proje için ağır ve fazla büyük bir

bataryadır. Daha ideal bir uygulama için daha verimli boyutlarda bir batarya

kullanıcının gözlüğü üzerine değil de iki gözlük sapı arasına yerleştirilerek ağırlık

dengesi daha iyi bir çözüm gerçekleştirilebilir.

Şekil 3.2.1: Kullanıcı tarafından görülen görüntü örneği

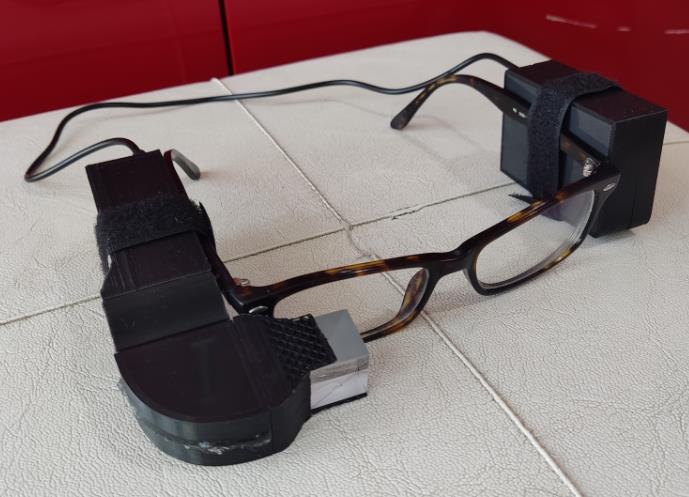
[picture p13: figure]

16

## 4.SONUÇLAR VE YORUMLAR

Şekil 4.1: Bluetooth Tabanlı Harici Akıllı Gözlük Aparatı

Bluetooth Tabanlı Harici Akıllı Gözlük Aparatı Projesi boyunca başarılı bir prototip ürün üretildi. Üretim aşamasında tasarımın kusurları sürekli olarak düzeltildi

ve geliştirildi. Bu geliştirmeler sonucu projenin başlangıcında planlanandan daha

farklı bir tasarım olmasına rağmen belirlenen özelliklere ve işlevselliklere ulaşıldı.

Görüntü çıktıları kullanıcı tarafından rahatlık ile okunabilir hale getirildi. Bu sayede,

kullanıcının günlük hayatını etkilemeden talep edilen bilgileri görebileceği arayüz

başarı ile oluşturulmuş oldu. Mobil cihaz uygulamasında ise istenilen otomatik

işlemler gerçekleştirilemedi. Eşitleme işlemleri mobil cihaz uygulaması ile manuel bir

operasyon ile gerçekleştirilmektedir.

Bu proje sürecinde Elektronik Mühendisliği bölümünden öğrenmiş olduğumuz

bilgilerimizin üzerine, bilgisayar tabanlı modelleme, optik çözümler ve ürün üretim

alanlarında da bilgiler edinerek yeteneklerimizi geliştirmiş bulunduk.

17

## 5. ÖNERİLER VE GELİŞTİRMELER

Optik çözümde daha optimize tasarımlar elde edinilebilir durumdadır. Kullanılan

ekrana kıyasla daha yüksek bir parlaklığa sahip bir ekran sayesinde 50:50 oranlı bir

prizma yerine 70:30 oranlı bir prizma kullanılıp, %70 geçirgenliğe sahip kısım

dışarından gelen ortam ışığını alacak şekilde konumlandırıldığında bu projedeki

çözüme kıyas ile arka plan görüntüsünü daha az karartan bir arayüz elde edilebilir.

Görüntü yansıtma metodu olarak aynalama kullanılmadan direkt ışın ayırıcı prizmaya

görüntü verilebilir veya projeksiyon metotları da uygulanabilir. Batarya ve batarya şarj

üniteleri kullanılan güç miktarına göre boyut ve fiyat olarak optimize edilebilir. Çeşitli

elektronik elementlerin konumlandırmaları ağırlık dengesi açısından geliştirilebilir. Özel üretim devre kartları ile ürünün boyutu ve ağırlığı azaltılabilir.

## 6.KAYNAKÇA

[1] Rizea, Adrian & Popescu, I.M.. (2012). Design techniques for all-dielectric

polarizing beam splitter cubes, under constrained situations. Romanian Reports in

Physics. 64. 482-491.

[2] Zuk, S., Pietrikova, A. and Vehec, I. (2018), "Capacitive touch sensor",
Microelectronics | International, | Vol. | 35 | No. | 3, | pp. | 153-157.

https://doi.org/10.1108/MI-12-2017-0071

[3] | ESP32-WROOM-32D | & | ESP32-WROOM-32U | Datasheet, | Espressif,

https://www.espressif.com/sites/default/files/documentation/esp32-wroom-

32d_esp32-wroom-32u_datasheet_en.pdf (https://www.espressif.com/sites/default/files/documentation/esp32-wroom-32d_esp32-wroom-32u_datasheet_en.pdf)

[4] TFT LCD MODULE 0.96 inch 80RGB*160DOTS, Zhong JY, https://www.smart-

prototyping.com/image/data/2020/11/102105%200.96%20TFT%20IPS%20Display

%20Module%20/Datasheet.pdf (https://www.smart-prototyping.com/image/data/2020/11/102105%200.96%20TFT%20IPS%20Display%20Module%20/Datasheet.pdf)

[5] SimpleBluetoothTerminal, Kai Morich, https://github.com/kai-

morich/SimpleBluetoothTerminal (https://github.com/kai-morich/SimpleBluetoothTerminal)

## EKLER

Ek A: Main.cpp

#include <Arduino.h>

#include <BluetoothSerial.h> #include <BluetoothUtils.h> #include <DisplayUtils.h>

#include <GlassUtils.h>

#include <Adafruit_SSD1306.h> #include <SPI.h>

#include <TFT_eSPI.h>

GlassUtils Glass;

void setup()
{
Serial.begin(115200);

Glass.Bluetooth.Begin();
Glass.StartBluetoothWriteToBufferTask();

Glass.Display.Begin();
Glass.StartDisplayTask();
Glass.StartDisplayUpdateTimeTask(); Glass.StartIOUpdateIOTask();
}

void loop()
{

}

Ek B: GlassUtils.cpp

#include <Arduino.h>

#include <BluetoothSerial.h> #include <BluetoothUtils.h> #include <GlassUtils.h>

#include <DisplayUtils.h>

#include <Adafruit_SSD1306.h> #include <SPI.h>

#include <TFT_eSPI.h>

using namespace Bluetooth;

GlassUtils::GlassUtils()
{
update_flag = true;
button_flag = false;
}

GlassUtils::~GlassUtils()
{

}

// BLUETOOTH TASKS

// WRITE TO BUFFER
void GlassUtils::BluetoothWriteToBufferTask() {
for(;;)
{
if(Bluetooth.Available())
{
// sets update flag if the bluetooth transmission is recieved Bluetooth.WriteToBuffer();
// parse the bluetooth transmission Display.ParseBT(Bluetooth.buffer.get(), Bluetooth.buffer_size, this->update_flag);
}
else
{
/*
for(size_t ii=0; ii<Bluetooth.buffer_size; ++ii) {
Serial.write(Bluetooth.buffer[ii]);
}
*/
vTaskDelay(1000 / portTICK_PERIOD_MS); }
}
}

void GlassUtils::StartBluetoothWriteToBufferTaskImpl(void* _this) {
((GlassUtils*)_this)->BluetoothWriteToBufferTask();
}

void GlassUtils::StartBluetoothWriteToBufferTask() {
xTaskCreate
(
this->StartBluetoothWriteToBufferTaskImpl, //func ptr "StartBTBuffer", //task name
8192, //stack size
(void*) this, //task parameters
2, //task priority
NULL //task handle
);
}

// DISPLAY TASKS

void GlassUtils::DisplayTask() {
for(;;)
{
Display.Refresh(this->update_flag, this->button_flag); vTaskDelay(1000 / portTICK_PERIOD_MS);
}
}

void GlassUtils::StartDisplayTaskImpl(void* _this)

{
((GlassUtils*)_this)->DisplayTask(); }

void GlassUtils::StartDisplayTask() {
xTaskCreate
(
this->StartDisplayTaskImpl, //func ptr "StartDPTest", //task name
65536, //stack size
(void*) this, //task parameters
1, //task priority
NULL //task handle
);
}

// TIME

void GlassUtils::DisplayUpdateTimeTask() {
for(;;)
{
Display.UpdateTime(this->update_flag); vTaskDelay(1000 / portTICK_PERIOD_MS);
}
}

void GlassUtils::StartDisplayUpdateTimeTaskImpl(void* _this) {
((GlassUtils*)_this)->DisplayUpdateTimeTask();
}

void GlassUtils::StartDisplayUpdateTimeTask()
{
xTaskCreate
(
this->StartDisplayUpdateTimeTaskImpl, //func ptr "StartTimeTest", //task name
1024, //stack size
(void*) this, //task parameters
1, //task priority
NULL //task handle
);
}

// IO

void GlassUtils::IOUpdateIOTask() {
for(;;)
{
IO.UpdateIO(this->update_flag, this->button_flag); vTaskDelay(200 / portTICK_PERIOD_MS);
}
}

void GlassUtils::StartIOUpdateIOTaskImpl(void* _this) {

((GlassUtils*)_this)->IOUpdateIOTask(); }

void GlassUtils::StartIOUpdateIOTask()
{
xTaskCreate
(
this->StartIOUpdateIOTaskImpl, //func ptr "StartUpdateIO", //task name
1024, //stack size
(void*) this, //task parameters
2, //task priority
NULL //task handle
);
}

Ek C: GlassUtils.h

#pragma once

#include <Arduino.h>

#include <BluetoothSerial.h> #include <BluetoothUtils.h> #include <DisplayUtils.h>

#include <IOUtils.h>

#include <Adafruit_SSD1306.h>

using namespace Bluetooth; using namespace Display;
using namespace IO;

class GlassUtils
{
public:
GlassUtils();
~GlassUtils();

void StartBluetoothWriteToBufferTask();
static void StartBluetoothWriteToBufferTaskImpl(void* _this); void BluetoothWriteToBufferTask();

void StartDisplayTask();
static void StartDisplayTaskImpl(void* _this);
void DisplayTask();

void StartDisplayUpdateTimeTask();
static void StartDisplayUpdateTimeTaskImpl(void* _this); void DisplayUpdateTimeTask();

void StartIOUpdateIOTask();
static void StartIOUpdateIOTaskImpl(void* _this);
void IOUpdateIOTask();

bool update_flag;
bool button_flag;

BluetoothUtils Bluetooth;
DisplayUtils Display;
IOUtils IO;

};

Ek D: DisplayUtils.cpp

#include <Arduino.h>

#include <BluetoothSerial.h> #include <BluetoothUtils.h> #include <GlassUtils.h>

#include <DisplayUtils.h>

#include <Adafruit_SSD1306.h> #include <SPI.h>

#include <TFT_eSPI.h>

#include <FS.h>

#include <SPIFFS.h>

#define GLASS_DEBUG

namespace Display
{

DisplayUtils::DisplayUtils() : tft()
{
// initial state for the display current_state = display_state::main_screen; // initial values for the display
hour = 0;
minute = 0;
second = 0;

time_x = 0;
time_y = 0;

date_x = 60;
date_y = 0;

sender_x = 0;
sender_y = 10;

message_x = 0;
message_y = 20;

offset_x = 0;
offset_y = 0;

time_buffer_size = 6;
time_buffer = std::unique_ptr<char>(new char[time_buffer_size]); sprintf(time_buffer.get(), "%02d:%02d", hour, minute); time_buffer.get()[time_buffer_size-1] = '\0';

sender_buffer_size = 64;
sender_buffer = std::unique_ptr<char>(new char[sender_buffer_size]); message_buffer_size = 128;
message_buffer = std::unique_ptr<char>(new char[message_buffer_size]);
sprintf(sender_buffer.get(),"Error"); sprintf(message_buffer.get(),"Last Message Not Found");

date_buffer_size = 8;

date_buffer = std::unique_ptr<char>(new char[date_buffer_size]);

show_message_counter = 0;
time_flag = false;
sender_flag = false;
message_flag = false;
show_message_flag = false; date_flag = false;
}

DisplayUtils::~DisplayUtils() {
tft.~TFT_eSPI();
}

void DisplayUtils::Begin() {
tft.init();
tft.setRotation(3);
}

void DisplayUtils::ParseBT(char* buffer, size_t buffer_size, bool& update_flag)
{
switch(buffer[0])
{
case 'T':
// if the packet tag is Time (-1 because first is reserved for 'T' tag)
this->hour = (((uint8_t) buffer[1] - 48) * 10) + (((uint8_t) buffer[2] - 48) * 1);
this->minute = (((uint8_t) buffer[3] - 48) * 10) + (((uint8_t) buffer[4] - 48) * 1); // parse values into a c string sprintf(time_buffer.get(), "%02d:%02d", hour, minute); time_buffer.get()[time_buffer_size-1] = '\0'; time_flag = true;
break;

case 'S':
// if the packet tag is Sender (-1 because first is reserved for 'S' tag)
memset(sender_buffer.get(), ' ', sender_buffer_size); strncpy(sender_buffer.get(), (buffer+1), sender_buffer_size);
sender_buffer.get()[sender_buffer_size-1] = '\0'; sender_flag = true;
break;

case 'M':
// if the packet tag is Message (-1 because first is reserved for 'M' tag)
memset(message_buffer.get(), ' ', message_buffer_size); strncpy(message_buffer.get(), (buffer+1), message_buffer_size-1);
message_buffer.get()[message_buffer_size-1] = '\0'; message_flag = true;
break;

case 'D':
// if the packet tag is Date (-1 because first is reserved for 'D' tag)
memset(date_buffer.get(), ' ', date_buffer_size); strncpy(date_buffer.get(), (buffer+1), date_buffer_size-1); date_buffer.get()[date_buffer_size-1] = '\0';
date_flag = true;
break;

case 'X':
{
// if the packet tag is X offset (-1 because first is reserved for 'X' tag)
uint8_t end_index = 0;
for(int ii=0; ii<buffer_size; ++ii)
{
if(buffer[ii] == ' ')
{
end_index = ii;
break;
}
}

#ifdef GLASS_DEBUG

Serial.printf("end index: %d\n", end_index); #endif

switch (end_index)
{
case 2:
this->offset_x = (((uint8_t) buffer[1] - 48) * 1); break;

case 3:
this->offset_x = (((uint8_t) buffer[1] - 48) * 10) + (((uint8_t) buffer[2] - 48) * 1); break;

case 4:
this->offset_x = (((uint8_t) buffer[1] - 48) * 100) + (((uint8_t) buffer[2] - 48) * 10) + (((uint8_t) buffer[3] - 48) * 1); break;

default:
// failed to assign to offset values break;
}

#ifdef GLASS_DEBUG

Serial.printf("offset_x: %d\n", offset_x); #endif

break;
}

case 'Y':
{
// if the packet tag is X offset (-1 because first is reserved for 'X' tag)

uint8_t end_index = 0;
for(int ii=0; ii<buffer_size; ++ii) {
if(buffer[ii] == ' ')
{
end_index = ii;
break;
}
}

#ifdef GLASS_DEBUG

Serial.printf("end index: %d\n", end_index); #endif

switch (end_index)
{
case 2:
this->offset_y = (((uint8_t) buffer[1] - 48) * 1); break;

case 3:
this->offset_y = (((uint8_t) buffer[1] - 48) * 10) + (((uint8_t) buffer[2] - 48) * 1); break;

case 4:
this->offset_y = (((uint8_t) buffer[1] - 48) * 100) + (((uint8_t) buffer[2] - 48) * 10) + (((uint8_t) buffer[3] - 48) * 1); break;

default:
// failed to assign to offset values break;
}

#ifdef GLASS_DEBUG

Serial.printf("offset_y: %d\n", offset_y); #endif

break;
}

default:
// tag not known
break;
}

if(sender_flag && message_flag) {
show_message_flag = true;
show_message_counter = 10; }

#ifdef GLASS_DEBUG

Serial.print(buffer[0]);
Serial.print(buffer[1]);
Serial.print(buffer[2]);
Serial.print(buffer[3]);
Serial.print(buffer[4]);

Serial.print('\n');
#endif

#ifdef GLASS_DEBUG

// update flag for screen refresh Serial.print("flag set\n"); #endif

// set update flag
update_flag = true;
}

void DisplayUtils::UpdateTime(bool& update_flag) {
if(time_flag)
{
++second;
if(second == 60)
{
second = 0;
++minute;
#ifdef GLASS_DEBUG

Serial.write("time refresh\n");
#endif

sprintf(time_buffer.get(), "%02d:%02d", hour, minute); time_buffer.get()[time_buffer_size-1] = '\0';
// if change is visible return update flag as true update_flag = true;
}
if(minute == 60)
{
minute = 0;
++hour;
#ifdef GLASS_DEBUG

Serial.write("time refresh\n");
#endif

sprintf(time_buffer.get(), "%02d:%02d", hour, minute); time_buffer.get()[time_buffer_size-1] = '\0';
// if change is visible return update flag as true update_flag = true;
}
if(hour == 24)
{
hour = 0;
#ifdef GLASS_DEBUG

Serial.write("time refresh\n");
#endif

sprintf(time_buffer.get(), "%02d:%02d", hour, minute); time_buffer.get()[time_buffer_size-1] = '\0';
// if change is visible return update flag as true update_flag = true;
}
}

// message counter update
if(sender_flag && message_flag && (show_message_counter == 0)) {
sender_flag = false;
message_flag = false;

show_message_flag = false; }
else
{
show_message_counter--;
}
}

void DisplayUtils::Refresh(bool& update_flag, bool& button_flag) {
// check update flag
if(update_flag)
{
#ifdef GLASS_DEBUG

Serial.write("screen refresh\n"); #endif

if(button_flag)
{
switch(current_state)
{
case display_state::main_screen:
current_state = display_state::last_notification; break;

case display_state::last_notification:
current_state = display_state::status_screen; break;

case display_state::status_screen:
current_state = display_state::test;
break;

default:
current_state = display_state::main_screen; break;
}
button_flag = false;
}

switch(current_state)
{
case display_state::main_screen: tft.fillScreen(TFT_BLACK); if(time_flag)
{
tft.setTextSize(2);
tft.drawString(time_buffer.get(), offset_x + time_x, offset_y + time_y);
}
if(date_flag)
{
tft.setTextSize(1);
tft.drawString(date_buffer.get(), offset_x + date_x, offset_y + date_y);
}
if(show_message_flag)
{
tft.setTextSize(1);

tft.drawString("New Message", offset_x + time_x, offset_y + time_y + 17);
tft.drawString("From: ", offset_x + time_x, offset_y + time_y + 27);
tft.drawString(sender_buffer.get(), offset_x + sender_x + 30, offset_y + sender_y + 17); tft.drawString(message_buffer.get(), offset_x + message_x, offset_y + message_y + 17);
}
break;

case display_state::last_notification: tft.fillScreen(TFT_BLACK); tft.setTextSize(1);
if(time_flag)
{
tft.drawString(time_buffer.get(), offset_x + time_x, offset_y + time_y);
}
tft.drawString("Last Message", offset_x + time_x , offset_y + time_y + 10);
tft.drawString("From: ", offset_x + time_x, offset_y + time_y + 20);
tft.drawString(sender_buffer.get(), offset_x + sender_x + 30, offset_y + sender_y + 10); tft.drawString(message_buffer.get(), offset_x + message_x, offset_y + message_y + 10); break;

case display_state::status_screen: tft.fillScreen(TFT_BLACK); tft.setTextSize(1);
if(time_flag)
{
tft.drawString(time_buffer.get(), offset_x + time_x, offset_y + time_y);
}
tft.drawString("System Status", offset_x, offset_y + time_y + 10);
tft.drawString("BT On", offset_x, time_y + offset_y + 20);
break;

case display_state::test:
tft.fillScreen(TFT_BLACK);
tft.setTextSize(1);
tft.drawString("a1a2a3a4a5a6a7a8a9a1a2a3a4", 0 ,0); tft.drawString("b1b2b3b4b5b6b7b8b9b1b2b3b4", 0 ,15); tft.drawString("c1c2c3c4c5c6c7c8c9c1c2c3c4", 0 ,30); tft.drawString("d1d2d3d4d5d6d7d8d9d1d2d3d4", 0 ,45); tft.drawString("e1e2e3e4e5e6e7e8e9e1e2e3e4", 0 ,60); tft.drawString("f1f2f3f4f5f6f7f8f9f1f2f3f4", 0 ,75); break;
}
// clear update flag after refresh update_flag = false;
#ifdef GLASS_DEBUG

Serial.write("flag cleared\n"); #endif

}
else
{
// do nothing
}
}

}

Ek E: DisplayUtils.h

#pragma once

#include <Arduino.h>

#include <BluetoothSerial.h> #include <BluetoothUtils.h> #include <Adafruit_SSD1306.h> #include <SPI.h>

#include <TFT_eSPI.h>

namespace Display
{

class DisplayUtils
{
public:
DisplayUtils();
~DisplayUtils();

void Begin();
void Refresh(bool&, bool&);
void ParseBT(char*, size_t, bool&);
void UpdateTime(bool&);

enum class display_state:uint8_t { main_screen = 0, last_notification = 1, status_screen = 2, test = 3}; display_state current_state;

uint8_t hour;
uint8_t minute;
uint8_t second;

uint8_t time_x;
uint8_t time_y;

uint8_t date_x;
uint8_t date_y;

uint8_t sender_x;
uint8_t sender_y;

uint8_t message_x;
uint8_t message_y;

uint8_t offset_x;
uint8_t offset_y;

std::unique_ptr<char> time_buffer; size_t time_buffer_size;

std::unique_ptr<char> sender_buffer; size_t sender_buffer_size; std::unique_ptr<char> message_buffer; size_t message_buffer_size; std::unique_ptr<char> date_buffer; size_t date_buffer_size;

size_t show_message_counter; bool time_flag;
bool sender_flag;
bool message_flag;
bool date_flag;
bool show_message_flag;

private:
TFT_eSPI tft;
};
} //namespace

Ek F: BluetoothUtils.cpp

#include <Arduino.h>

#include <BluetoothSerial.h> #include <BluetoothUtils.h> #include <GlassUtils.h>

#include <DisplayUtils.h>

#include <Adafruit_SSD1306.h> #include <SPI.h>

#include <TFT_eSPI.h>

namespace Bluetooth
{

BluetoothUtils::BluetoothUtils() : SerialBT()
{
// define buffer size to hold the bluetooth data buffer_size = 128;
// allocate buffer using unique pointer
buffer = std::unique_ptr<char>(new char [buffer_size]); }

BluetoothUtils::~BluetoothUtils()
{
// call destructor for member subclass SerialBT.~BluetoothSerial();
}

void BluetoothUtils::Begin()
{
// initialize serial bluetooth communication SerialBT.begin("Smart Glass V1.0");
}

void BluetoothUtils::WriteToBuffer()
{
// if there is a message inbound if(this->Available())
{

// resets old contents
memset(buffer.get(), ' ', buffer_size);
// writes the incoming telemetry to buffer SerialBT.readBytes(buffer.get(), buffer_size);

#ifdef GLASS_DEBUG

for(int i=0; i<buffer_size; i++)
{
Serial.print(buffer[i]);
}
Serial.print('\n');
#endif

}
else
{
// do nothing
}
}

bool BluetoothUtils::Available()
{
// return bluetooth availability return SerialBT.available();
}
}; // namespace

Ek G: BluetoothUtils.h

#pragma once

#include <Arduino.h>

#include <BluetoothSerial.h> #include <DisplayUtils.h>

#include <Adafruit_SSD1306.h>

namespace Bluetooth
{

class BluetoothUtils
{
public:
BluetoothUtils();
~BluetoothUtils();

void Begin();
void WriteToBuffer();
bool Available();

size_t buffer_size;
std::unique_ptr<char> buffer;

private:
BluetoothSerial SerialBT;
};
} //namespace

Ek H: IOUtils.cpp

#include <Arduino.h>

#include <BluetoothSerial.h> #include <SPI.h>

#include <IOUtils.h>

#define GLASS_DEBUG

namespace IO
{

IOUtils::IOUtils()
{
ignore_cycle = 0;
IOTouch = 0;
}

IOUtils::~IOUtils()
{

}

void IOUtils::UpdateIO(bool& update_flag, bool& button_flag) {
if(ignore_cycle != 0)
{
--ignore_cycle;
}

IOTouch = touchRead(T7);

#ifdef GLASS_DEBUG

Serial.println(IOTouch);
#endif

if(IOTouch < 15 && ignore_cycle == 0) {
button_flag = true;
update_flag = true;
ignore_cycle = 5; // 200ms delay per cycle, 1000 ms per check }
}

}

Ek I: IOUtils.h

#pragma once

#include <Arduino.h>

#include <BluetoothSerial.h> #include <SPI.h>

namespace IO
{

class IOUtils
{
public:
IOUtils();

~IOUtils();

void UpdateIO(bool&, bool&);

uint8_t ignore_cycle;
uint16_t IOTouch;

};

} //namespace

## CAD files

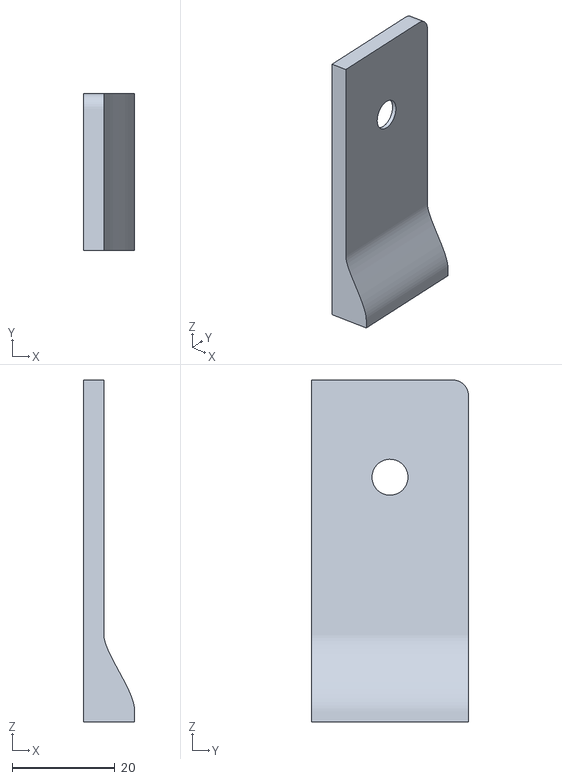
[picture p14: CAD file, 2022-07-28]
3D Models/Screen-Back-Long1.STL
10.0 x 30.5 x 66.5

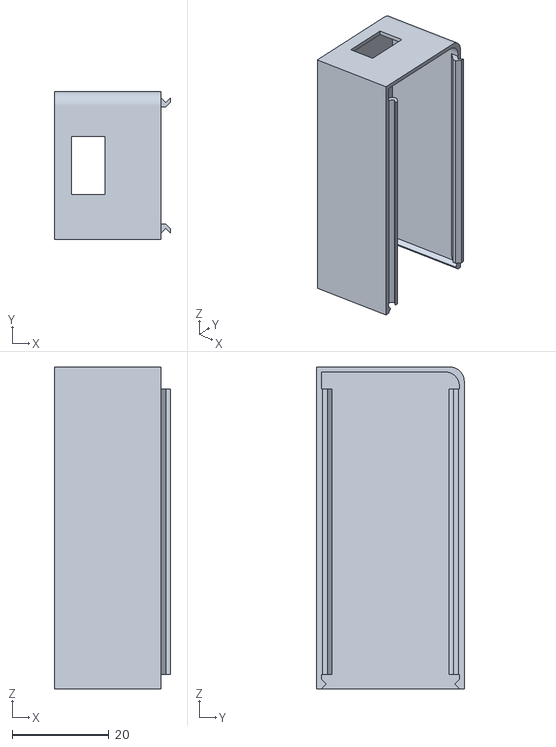
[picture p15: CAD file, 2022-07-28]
3D Models/Screen-Back-Long2.STL
24.0 x 30.5 x 66.5

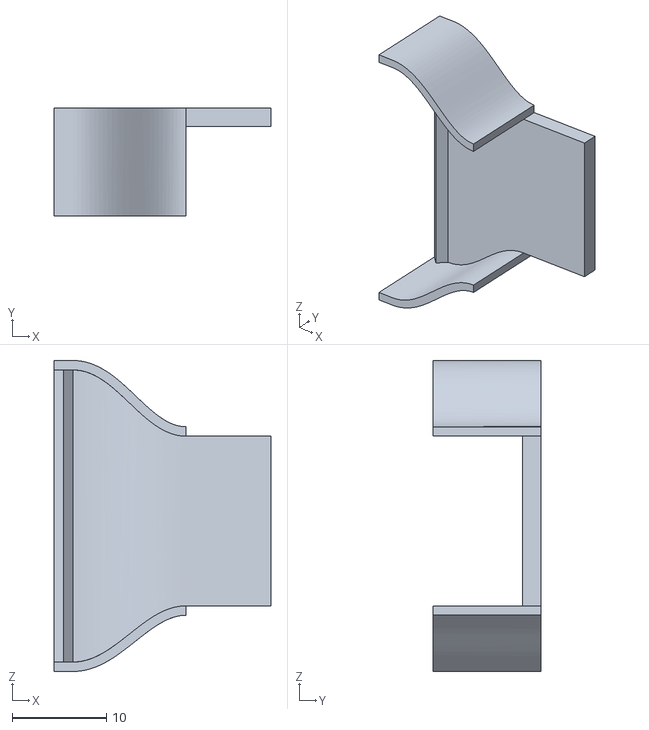
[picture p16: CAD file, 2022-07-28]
3D Models/Prism-Lens-Holder-Divided1.STL
23.0 x 11.5 x 33.0

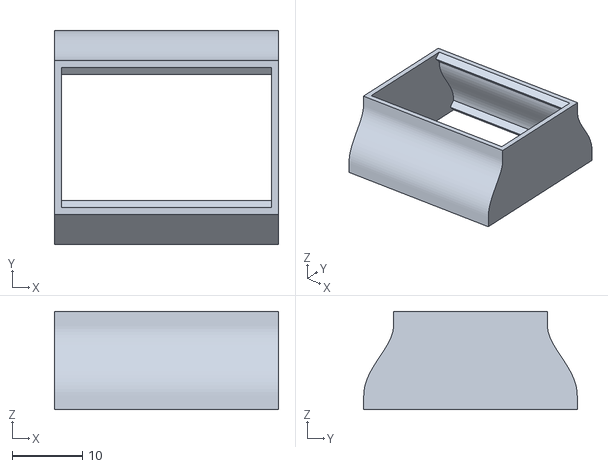
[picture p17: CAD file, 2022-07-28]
3D Models/Screen-Crop.STL
32.0 x 30.5 x 14.0

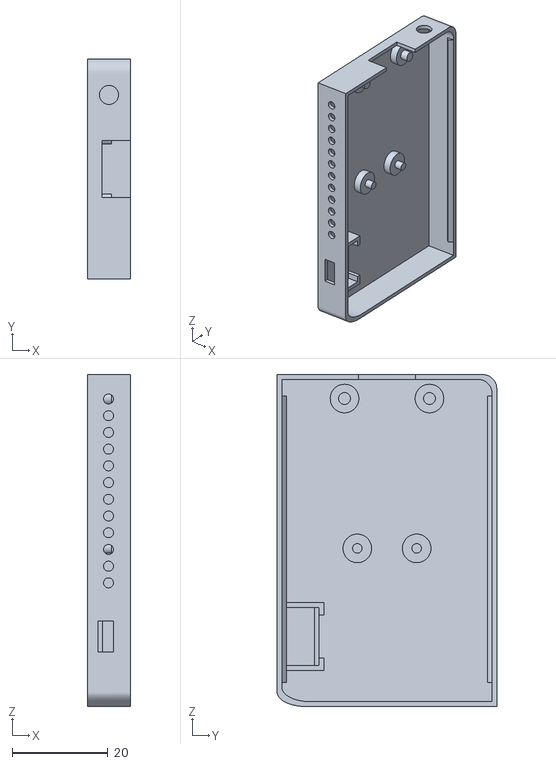
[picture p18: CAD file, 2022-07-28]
3D Models/Power-Long1.STL
9.00 x 46.0 x 69.5

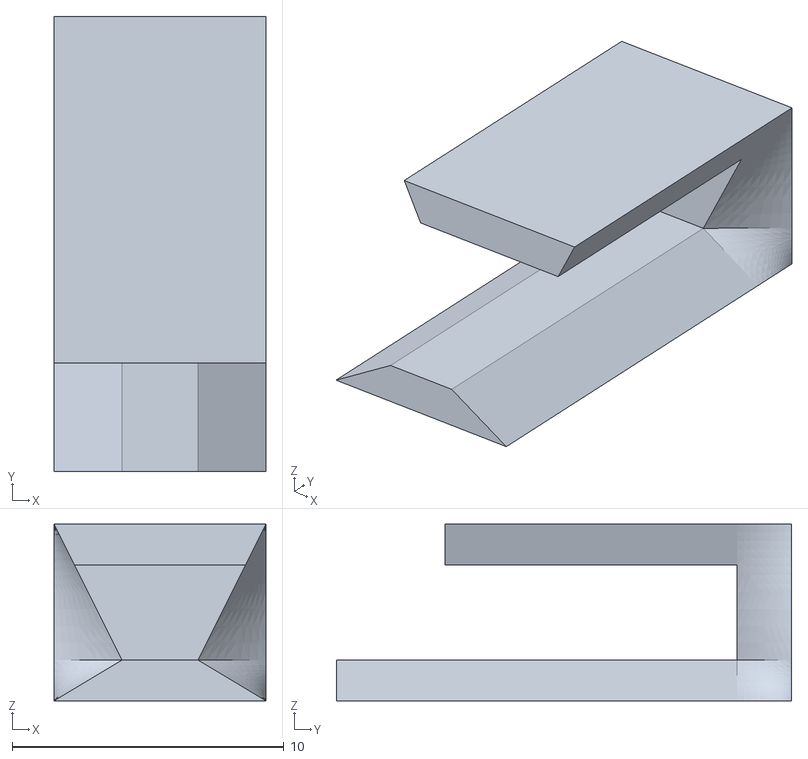
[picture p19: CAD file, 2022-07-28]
3D Models/Mounting.STL
7.80 x 16.8 x 6.50

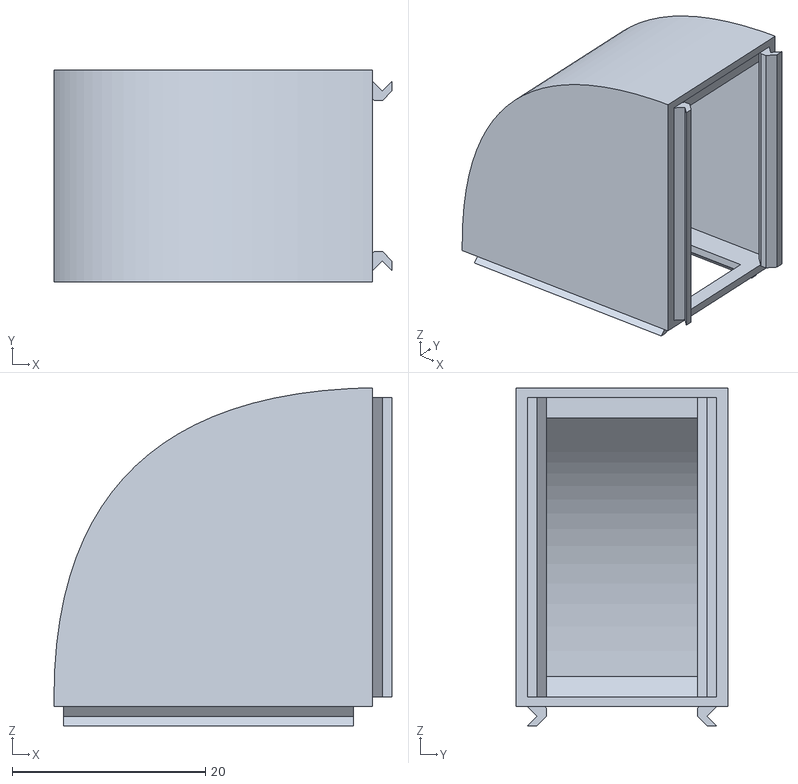
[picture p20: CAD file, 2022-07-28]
3D Models/Screen-Crop-Extension.STL
35.0 x 22.0 x 35.0

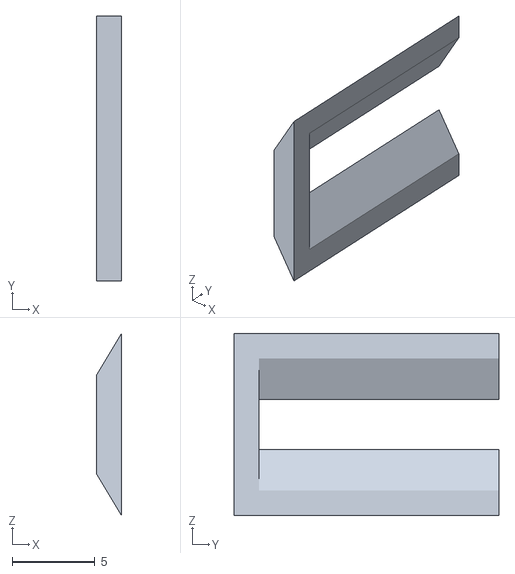
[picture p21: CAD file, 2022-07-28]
3D Models/Mounting-Slot.STL
1.50 x 16.0 x 11.0

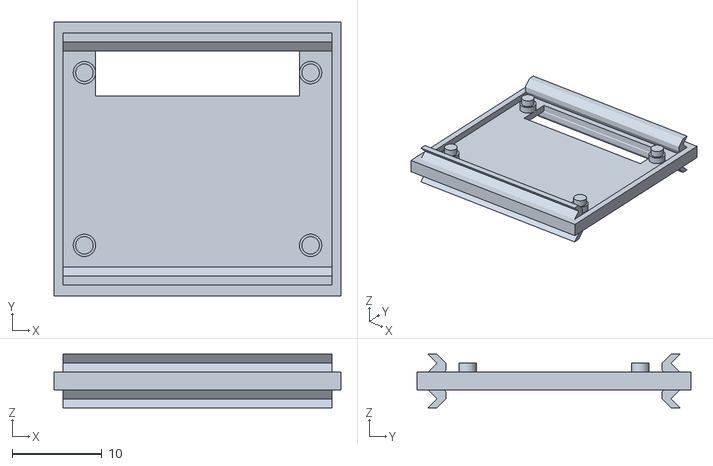
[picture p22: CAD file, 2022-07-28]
3D Models/Screen-Frame.STL
32.0 x 30.5 x 6.00

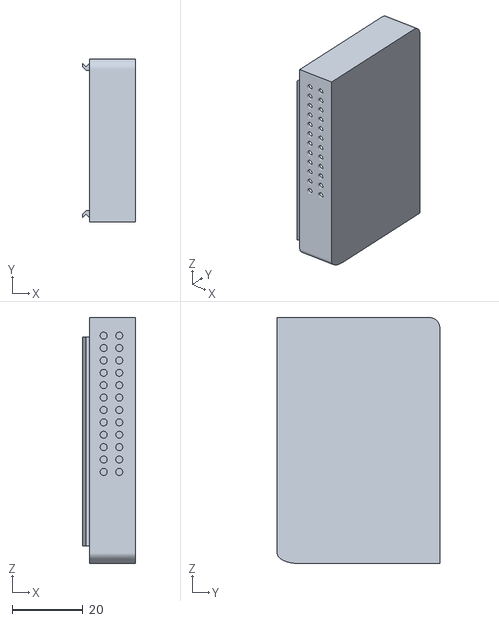
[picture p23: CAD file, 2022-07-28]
3D Models/Power-Long2.STL
15.0 x 46.0 x 69.5

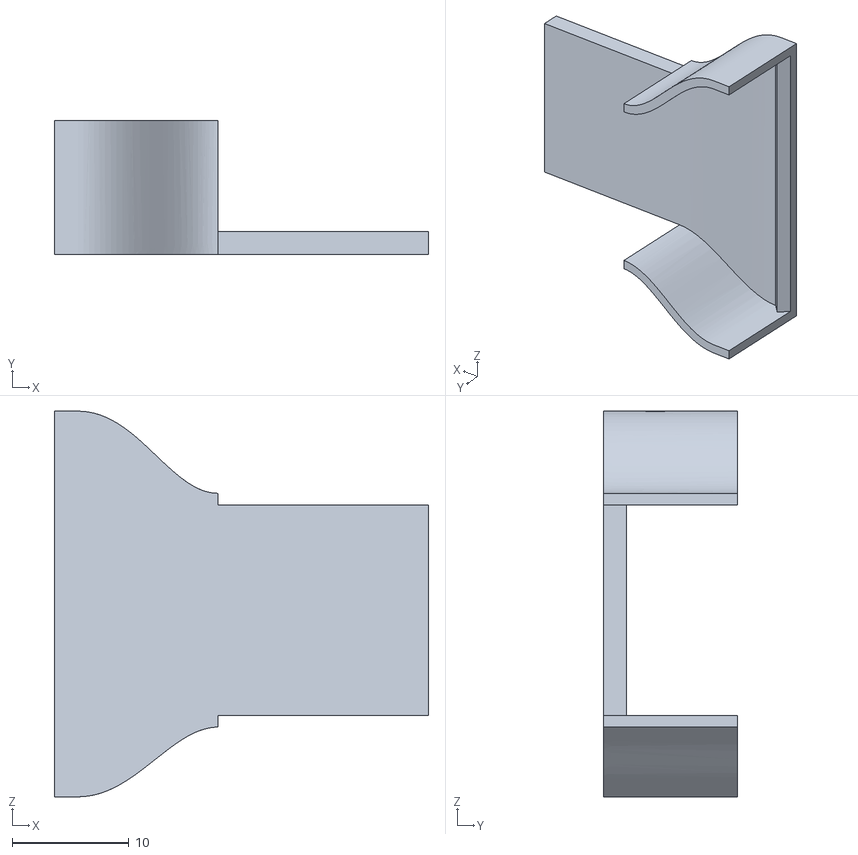
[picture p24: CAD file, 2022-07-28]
3D Models/Prism-Lens-Holder-Divided2.STL
32.0 x 11.5 x 33.0
